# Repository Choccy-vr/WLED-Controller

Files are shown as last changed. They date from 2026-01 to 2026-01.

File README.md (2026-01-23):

# WLED-Controller
An all-in-one controller for WS2812B LED strips, made for WLED. With Adapters for LEDs everywhere.

I made this because these WS2812B strips and WLED look so good, but all the other WLED controllers are quite expensive, and I would rather make it by myself. I set out to make it as small as possible, even if that means making it harder for me.

On the controller PCB, I integrated basically a esp32 c3 supermini. That is the bulk of it, but I also put some capacitors on the LED PWR line for smoothing the power out. I also added a P-channel MOSFET to allow for a soft start.

The various adapter PCBs adapt the specified port into 5v and GND and output it to a USB-C, inspired by Framework's modules

### Images:
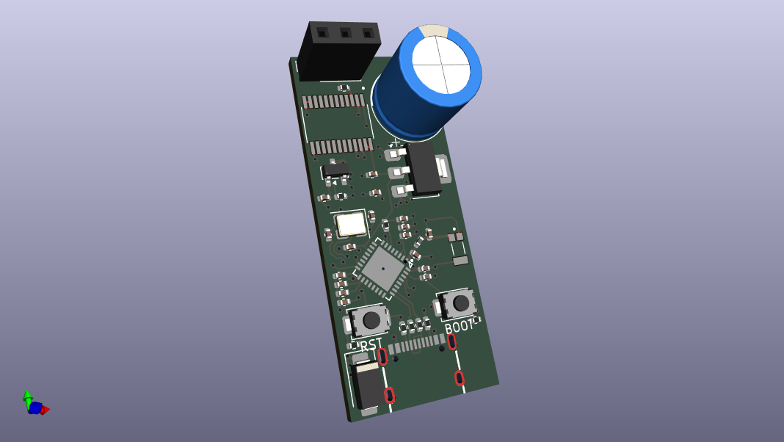
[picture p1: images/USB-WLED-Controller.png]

#### Schematic
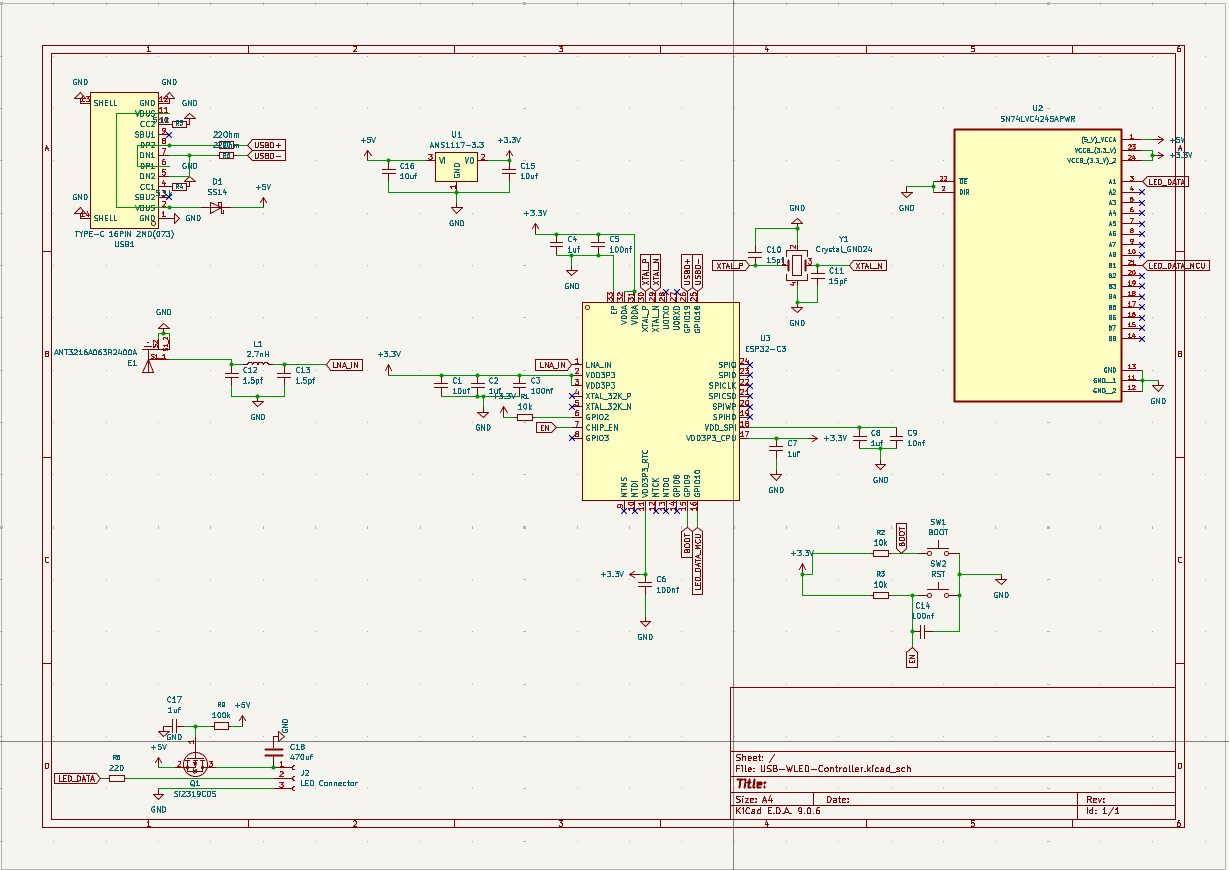
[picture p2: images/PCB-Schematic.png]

#### Adapters
##### SATA Adapter
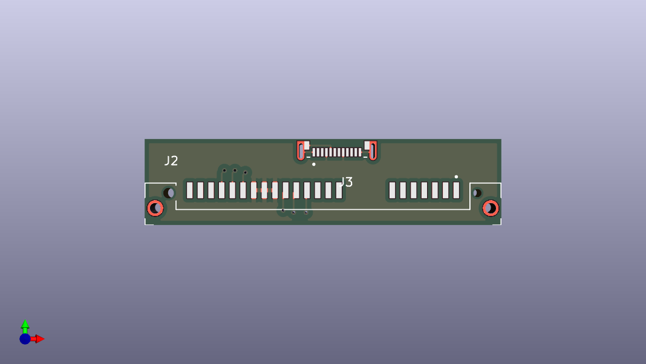
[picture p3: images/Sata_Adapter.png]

##### Barrel Jack Adapter
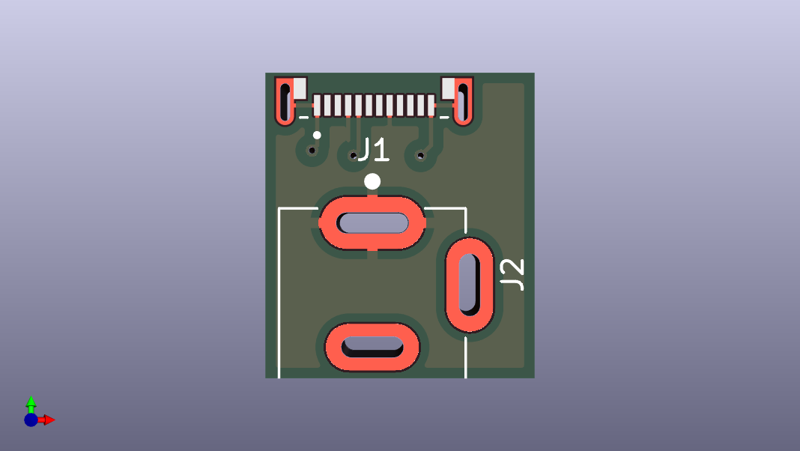
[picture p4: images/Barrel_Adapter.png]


### BOM
|Product Name |Product Description |Product Link |Product unit price|Product amount|Product Cost|Total (Before Tax + Shipping)|Total |
|---|---|---|---|---|---|---|---|
|Main PCB(A) |The main control PCB |https://jlcpcb.com/ |$8.71 |5 |$35.45 |$59.27 |$67.38|
|Sata Adapter PCB  |Sata adapter |https://jlcpcb.com/ |$1.02 |5 |$5.10 | | |
|Barrel Adapter PCB|Barrel adapter |https://jlcpcb.com/ |$1.02 |5 |$5.10 | | |
|Antenna |Antenna |https://www.digikey.com/en/products/detail/pulse-electronics/ANT3216A063R2400A/3927186 |$0.22 |1 |$0.22 | | |
|Bulk Cap |Cap for LEDs |https://www.digikey.com/en/products/detail/rubycon/35PX470MEFC10X12-5/3134236 |$0.34 |10 |$3.44 | | |
|Sata Connector |Connector for SATA PCB  |https://www.digikey.com/en/products/detail/amphenol-cs-fci/10034814-001LF/1001349 |$6.84 |1 |$6.84 | | |
|USB-C |Male USB C |https://www.digikey.com/en/products/detail/same-sky-formerly-cui-devices/UP20-C-F-G-FL-P12-TR/24818610|$1.30 |2 |$2.60 | | |
|Barrel Jack |Connector for Barrel PCB|https://www.digikey.com/en/products/detail/same-sky-formerly-cui-devices/PJ-002A/96962 |$0.52 |1 |$0.52 | | |

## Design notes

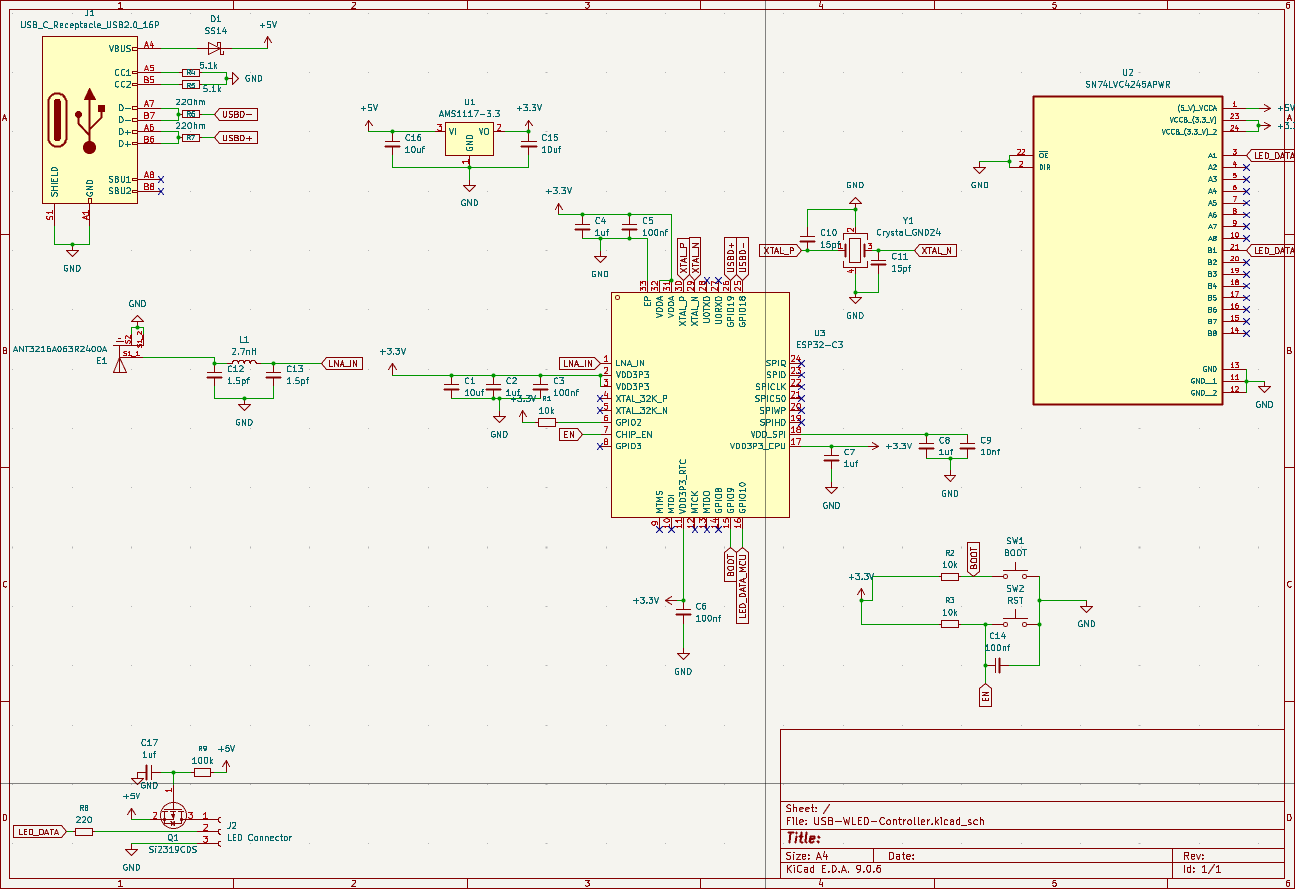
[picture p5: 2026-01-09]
PCB/USB/schematic.png

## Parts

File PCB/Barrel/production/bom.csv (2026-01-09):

Designator | Footprint | Quantity | Value | LCSC Part #
J1 | SAMESKY_UP20-C-F-G-FL-P12-TR | 1 | UP20-C-F-G-FL-P12-TR
J2 | CUI_PJ-002A | 1 | PJ-002A

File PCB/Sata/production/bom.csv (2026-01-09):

Designator | Footprint | Quantity | Value | LCSC Part #
J2 | AMPHENOL_10034814-001LF | 1 | 10034814-001LF
J3 | SAMESKY_UP20-C-F-G-FL-P12-TR | 1 | UP20-C-F-G-FL-P12-TR

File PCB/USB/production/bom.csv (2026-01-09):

Designator | Footprint | Quantity | Value | LCSC Part #
C1, C15, C16 | 0402 | 3 | 10uf | C15525
C10, C11 | 0402 | 2 | 15pf | C1548
C12, C13 | 0402 | 2 | 1.5pf | C1552
C14, C3, C5, C6 | 0402 | 4 | 100nf | C1525
C17, C2, C4, C7, C8 | 0402 | 5 | 1uf | C52923
C18 | CP_Radial_D10.0mm_P5.00mm | 1 | 470uf
C9 | 0402 | 1 | 10nf | C15195
D1 | D_SMA | 1 | SS14 | C2480
E1 | XDCR_ANT3216A063R2400A | 1 | ANT3216A063R2400A
J2 | PinSocket_1x03_P2.54mm_Vertical | 1 | LED Connector
L1 | 0402 | 1 | 2.7nH | C27123
Q1 | SOT-23 | 1 | Si2319CDS | C10487
R1, R2, R3 | 0402 | 3 | 10k | C25744
R4, R5 | 0402 | 2 | 5.1k | C25905
R6, R7 | 0402 | 2 | 22Ohm | C25092
R8 | 0402 | 1 | 220 | C25091
R9 | 0402 | 1 | 100k | C25741
SW1 | SW_SPST_TS-1088-xR020 | 1 | BOOT | C720477
SW2 | SW_SPST_TS-1088-xR020 | 1 | RST | C720477
U1 | SOT-223-3_TabPin2 | 1 | AMS1117-3.3 | C6186
U2 | SOP65P640X120-24N | 1 | SN74LVC4245APWR | C7859
U3 | QFN-32_L5.0-W5.0-P0.50-TL-EP3.7 | 1 | ESP32-C3 | C2838500
USB1 | USB-C-SMD_TYPE-C-6PIN-2MD-073 | 1 | TYPE-C 16PIN 2MD(073) | C2765186
Y1 | Crystal_SMD_3225-4Pin_3.2x2.5mm | 1 | Crystal_GND24 | C252255

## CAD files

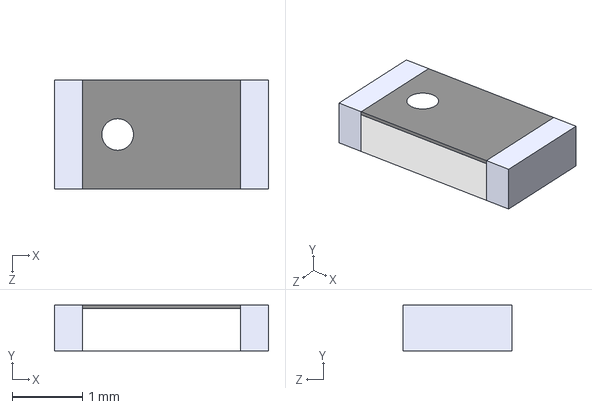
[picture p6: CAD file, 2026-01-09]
PCB/Resources/ANT3216A063R2400A/ANT3216A063R2400A.step
3.05 x 0.65 x 1.55 mm

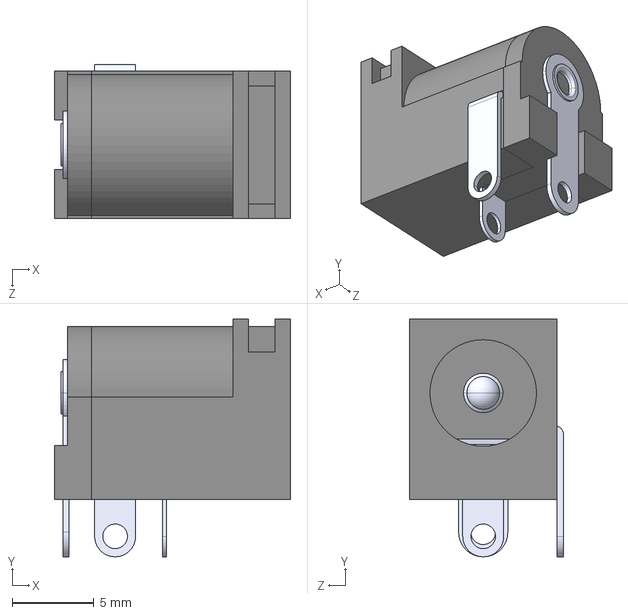
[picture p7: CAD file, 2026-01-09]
PCB/Resources/PJ_002A/PJ-002A.step
14.4 x 14.5 x 9.40 mm

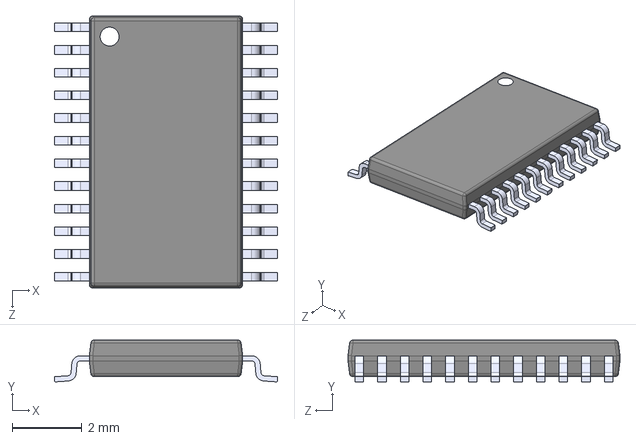
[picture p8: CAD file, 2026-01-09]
PCB/Resources/SN74LVC4245APWR/SN74LVC4245APWR.step
6.40 x 1.20 x 7.80 mm

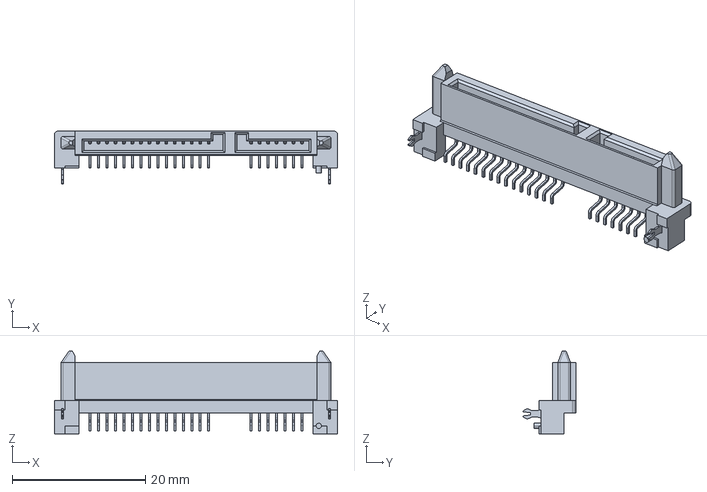
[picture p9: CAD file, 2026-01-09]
PCB/Resources/10034814_001LF/10034814-001LF.step
42.4 x 7.90 x 12.4 mm

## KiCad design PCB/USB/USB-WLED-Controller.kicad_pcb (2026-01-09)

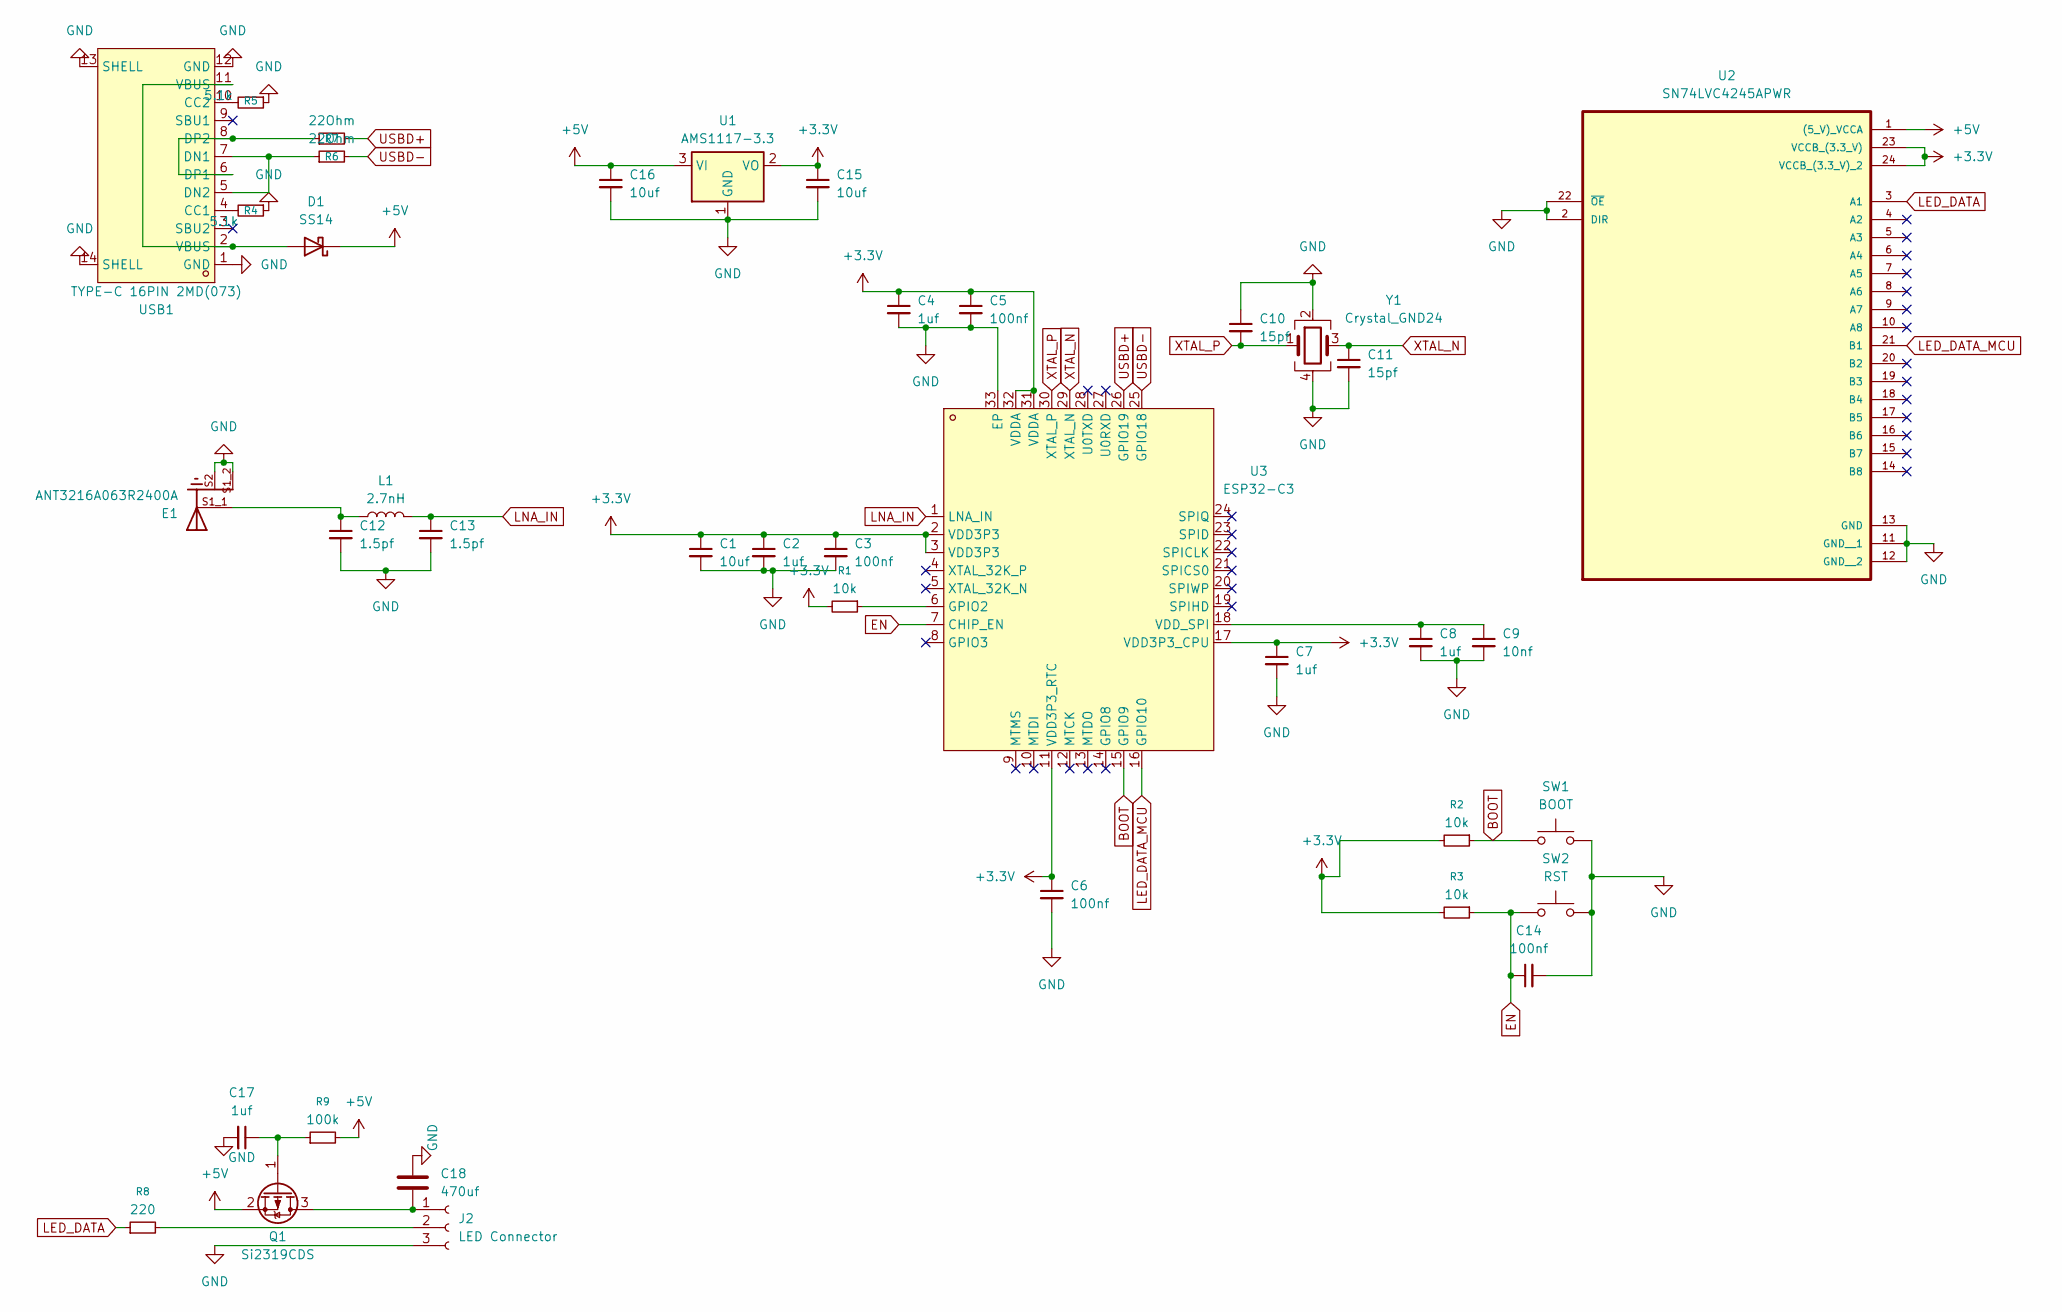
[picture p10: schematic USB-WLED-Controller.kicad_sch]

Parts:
C1, C15, C16: 10uf; C_0402_1005Metric; LCSC C15525
C2, C4, C7, C8, C17: 1uf; C_0402_1005Metric; LCSC C52923
C3, C5, C6, C14: 100nf; C_0402_1005Metric; LCSC C1525
C9: 10nf; C_0402_1005Metric; LCSC C15195
C10, C11: 15pf; C_0402_1005Metric; LCSC C1548
C12, C13: 1.5pf; C_0402_1005Metric; LCSC C1552
C18: 470uf; CP_Radial_D10.0mm_P5.00mm
D1: SS14; D_SMA; LCSC C2480
E1: ANT3216A063R2400A; XDCR_ANT3216A063R2400A; PARTREV 1
J2: LED Connector; PinSocket_1x03_P2.54mm_Vertical
L1: 2.7nH; L_0402_1005Metric; LCSC C27123
Q1: Si2319CDS; SOT-23; LCSC C10487
R1, R2, R3: 10k; R_0402_1005Metric; LCSC C25744
R4, R5: 5.1k; R_0402_1005Metric; LCSC C25905
R6, R7: 22Ohm; R_0402_1005Metric; LCSC C25092
R8: 220; R_0402_1005Metric; LCSC C25091
R9: 100k; R_0402_1005Metric; LCSC C25741
SW1: BOOT; SW_SPST_TS-1088-xR020; LCSC C720477
SW2: RST; SW_SPST_TS-1088-xR020; LCSC C720477
U1: AMS1117-3.3; SOT-223-3_TabPin2; LCSC C6186
U2: SN74LVC4245APWR; SOP65P640X120-24N; LCSC C7859
U3: ESP32-C3; QFN-32_L5.0-W5.0-P0.50-TL-EP3.7; LCSC Part C2838500
USB1: TYPE-C 16PIN 2MD(073); USB-C-SMD_TYPE-C-6PIN-2MD-073; LCSC Part C2765186
Y1: Crystal_GND24; Crystal_SMD_3225-4Pin_3.2x2.5mm; LCSC C252255

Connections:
+3.3V: C1.1, C2.1, C3.1, C4.1, C5.1, C6.1, C7.1, C15.1, R1.2, R2.2, R3.2, U1.2 (VO), U2.23 (VCCB_(3.3_V)), U2.24 (VCCB_(3.3_V)_2), U3.2 (VDD3P3), U3.3 (VDD3P3), U3.11 (VDD3P3_RTC), U3.17 (VDD3P3_CPU), U3.31 (VDDA), U3.32 (VDDA)
+5V: C16.1, D1.1 (K), Q1.2 (S), R9.2, U1.3 (VI), U2.1 ((5_V)_VCCA)
BOOT: R2.1, SW1.1, U3.15 (GPIO9)
EN: C14.1, R3.1, SW2.1, U3.7 (CHIP_EN)
GND: C1.2, C2.2, C3.2, C4.2, C5.2, C6.2, C7.2, C8.2, C9.2, C10.1, C11.2, C12.2, C13.2, C14.2, C15.2, C16.2, C17.2, C18.1, E1.S1_2, E1.S2, J2.3, R4.1, R5.1, SW1.2, SW2.2, U1.1 (GND), U2.2 (DIR), U2.11 (GND__1), U2.12 (GND__2), U2.13 (GND), U2.22 (~OE), U3.33 (EP), USB1.1 (GND), USB1.12 (GND), USB1.13 (SHELL), USB1.14 (SHELL), Y1.2, Y1.4
LED_DATA: R8.1, U2.3 (A1)
LED_DATA_MCU: U2.21 (B1), U3.16 (GPIO10)
LNA_IN: C13.1, L1.2, U3.1 (LNA_IN)
unnamed: C12.1, E1.S1_1, L1.1
unnamed: D1.2 (A), USB1.2 (VBUS), USB1.11 (VBUS)
unnamed: C18.2, J2.1, Q1.3 (D)
unnamed: J2.2, R8.2
unnamed: C17.1, Q1.1 (G), R9.1
unnamed: R1.1, U3.6 (GPIO2)
unnamed: C8.1, C9.1, U3.18 (VDD_SPI)
unnamed: R4.2, USB1.4 (CC1)
unnamed: R5.2, USB1.10 (CC2)
unnamed: R6.1, USB1.5 (DN2), USB1.7 (DN1)
unnamed: R7.1, USB1.6 (DP1), USB1.8 (DP2)
USBD+: R7.2, U3.26 (GPIO19)
USBD-: R6.2, U3.25 (GPIO18)
XTAL_N: C11.1, U3.29 (XTAL_N), Y1.3
XTAL_P: C10.2, U3.30 (XTAL_P), Y1.1

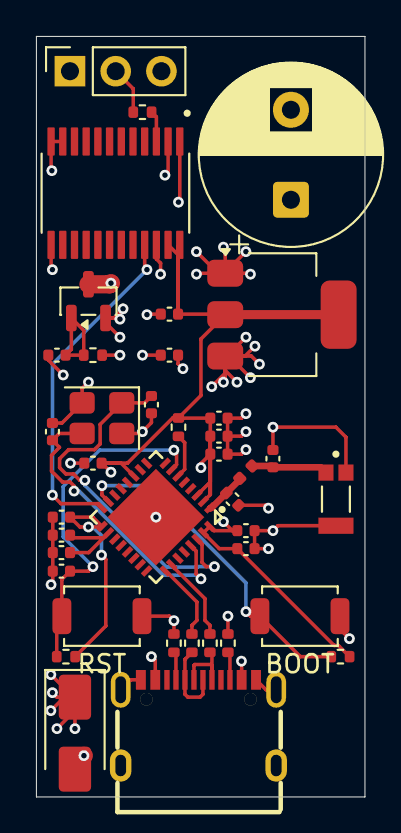
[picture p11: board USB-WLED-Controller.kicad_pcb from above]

Board: 4 copper layers, 18.2 x 42.3 mm, 39 parts (0 on the bottom side), 23 nets.

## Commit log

2026-01-09 Enhance README with project details and BOM
    Expanded the README with additional details about the project, including images, adapters, and a bill of materials (BOM).
2026-01-09 Fix total cost for Main PCB(A) in README
    Updated total cost for Main PCB(A) in the BOM.
2026-01-09 Update WLED Controller BOM.csv
    [WLED Controller BOM.csv]
2026-01-11 Enhance README with additional project details
    Expanded the project description to include details about the PCB integration and adapter PCBs.
2026-01-23 Fix cost for Main PCB(A) in BOM
    Updated the total cost for Main PCB(A) in the BOM.
    [WLED Controller BOM.csv]
2026-01-23 Revise BOM with updated product costs and totals
    Updated product costs and totals in the BOM section.
